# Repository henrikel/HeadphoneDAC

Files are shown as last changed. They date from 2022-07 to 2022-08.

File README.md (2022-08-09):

# HeadphoneDAC
This project started with the purchase of a couple of Chinese DAC modules designed around a PCM1794 DAC from TI. It turned out the DAC module was of quite good quality with genuine parts and a design closely following the datasheet reference design for the analog part. I therefore decided to make a headphone amplifier out of this with USB input. For this reason I had to design and construct the actual headphone amplifier as well as the logic that converts the USB data into an I2S stream that can be read by the DAC. A suitable power supply also had to be designed. All in all, the whole project therefore consists of 4 modules, one logic board with a STM32F411 running the show, one DAC module, one headphone amplifier module and one power supply.

The logic module takes care of converting the USB audio stream into I2S data on a USB full-speed interface. This sets a limit of the maximum sample rate to 96 kHz. It implements the proper way to handle the audio data, i.e., asynchronously. As of now, the system clock of the STM32 microcontroller is used for the audio clock, something that can be improved in the future. The STM32F411 microcontroller also takes care of the user interface, which consists of a few buttons and LEDs to indicate playback, mute and sampling rate. A LED VU meter is also implemented as well as control of a relay to avoid pops and clicks at startup and shutdown.

The headphone amplifier is a class A output design, using a NE5534 opamp as voltage amplifier and an emitter follower implemented as a Sziklai pair with a current sink. The design itself has borrowed from two sources, the Youtube channel Innove Workshop (but modified for dual supply) and Elliott Sound Products (https://sound-au.com/project113.htm). It is a relatively simple design, but measures well (I get THD figures of approximately 0.03% at 1 kHz and 100 mW, which is around the limit of my home made sound card using a Raspberry Pi and Hifiberry ADC+DAC). 

The power supply is a simple design giving +/-12 V and +5V, with a toroidal transformer and LM317/337 and L7812/7809/7805.

I am pretty happy with this build and think it sounds really good with my Beyerdynamic DT880 Pro headphones (250 ohms). I had some problems with ground loops and interference from the transformer in the case I built for the amplifier, but I think I have sorted out most of that now with some tweaking of the orientation of the transformer as well as appropriate grounding. What remains is an irritating high-pitched interference obviously coming from the digital parts of the controller module, which oddly enough can only be heard when muting the sound (if streaming is on, but no music is playing or very low levels of music, I can't hear it).
<p align="center">
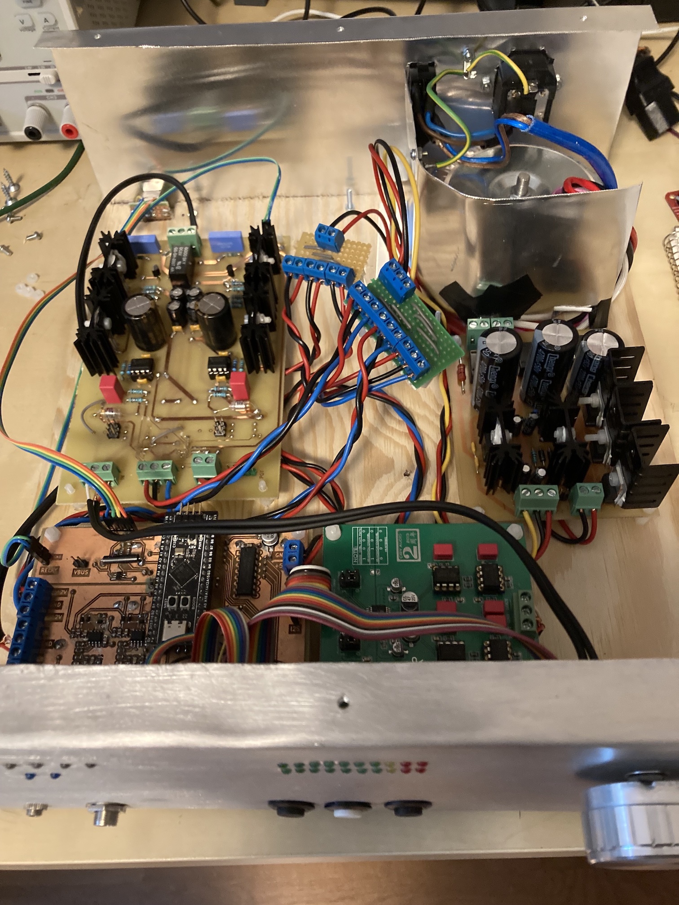
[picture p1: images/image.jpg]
Prototype
  
</p>

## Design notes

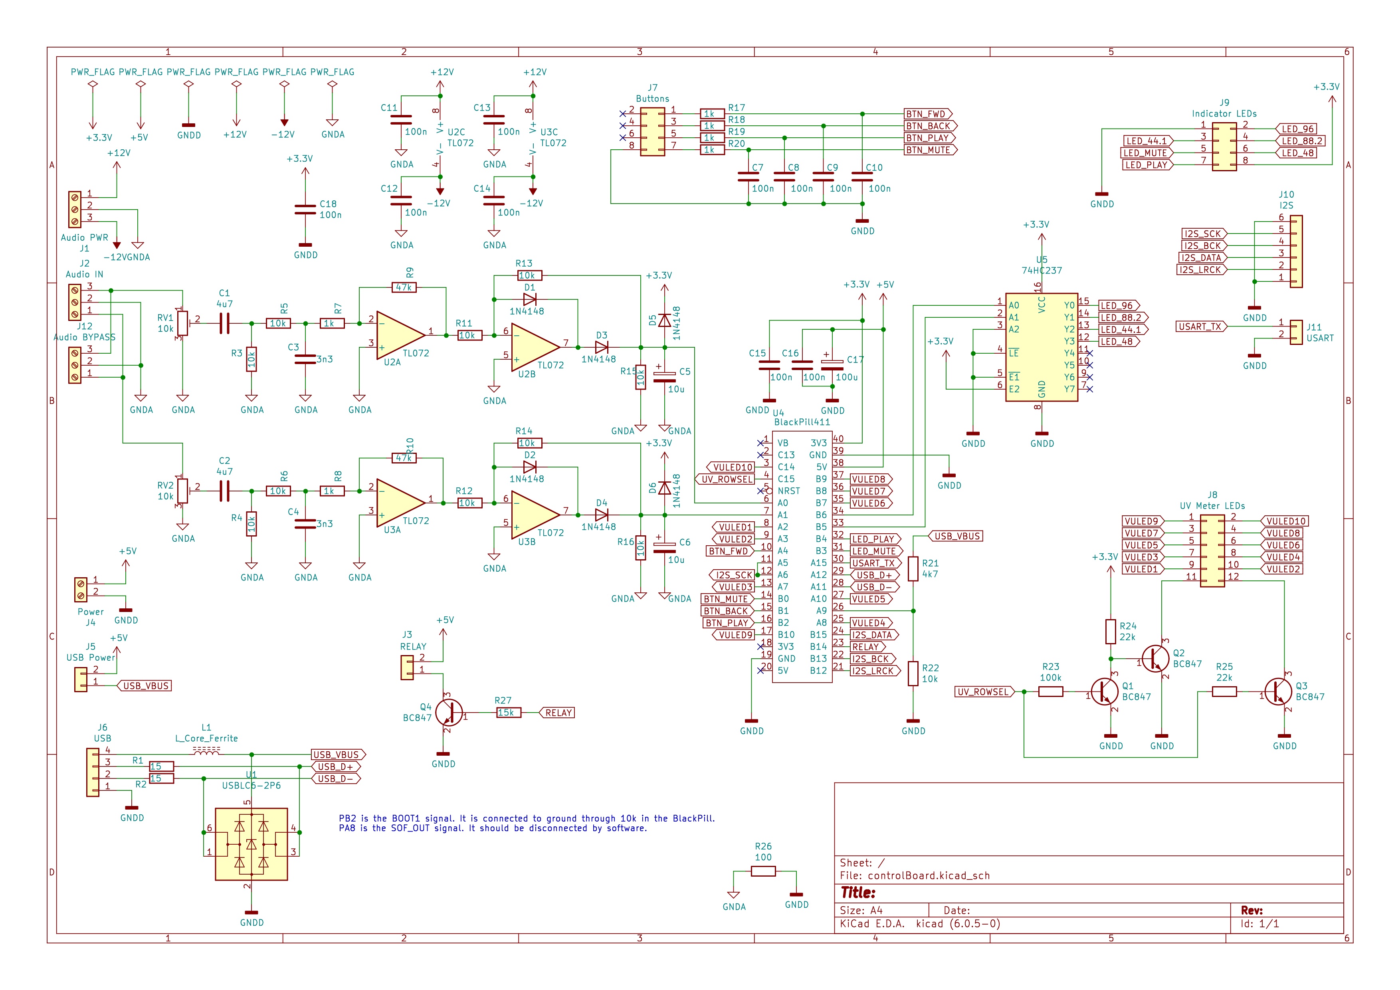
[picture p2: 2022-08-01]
hw/controlBoard/schematic.jpg

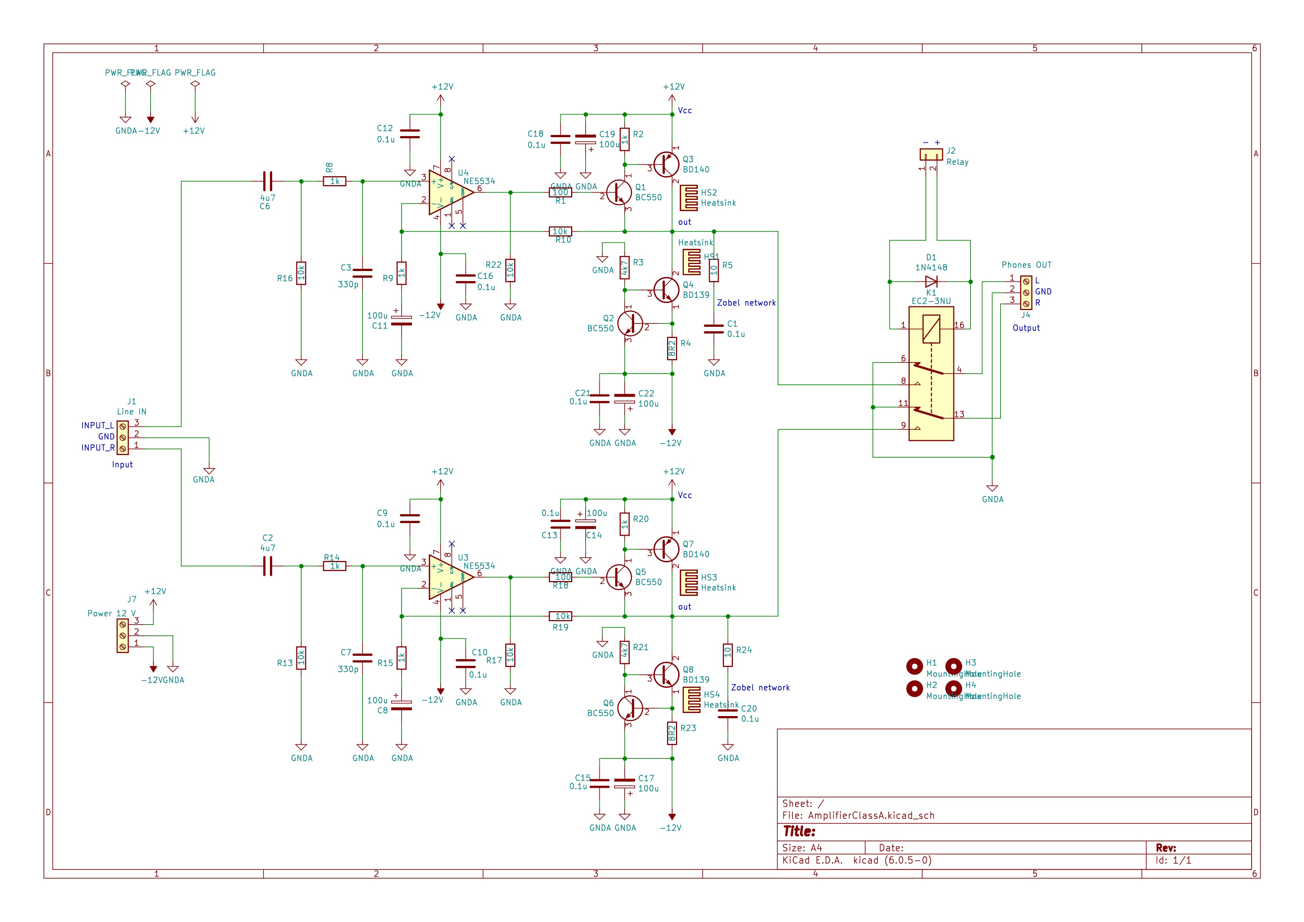
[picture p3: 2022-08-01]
hw/AmplifierClassA/schematic.jpg

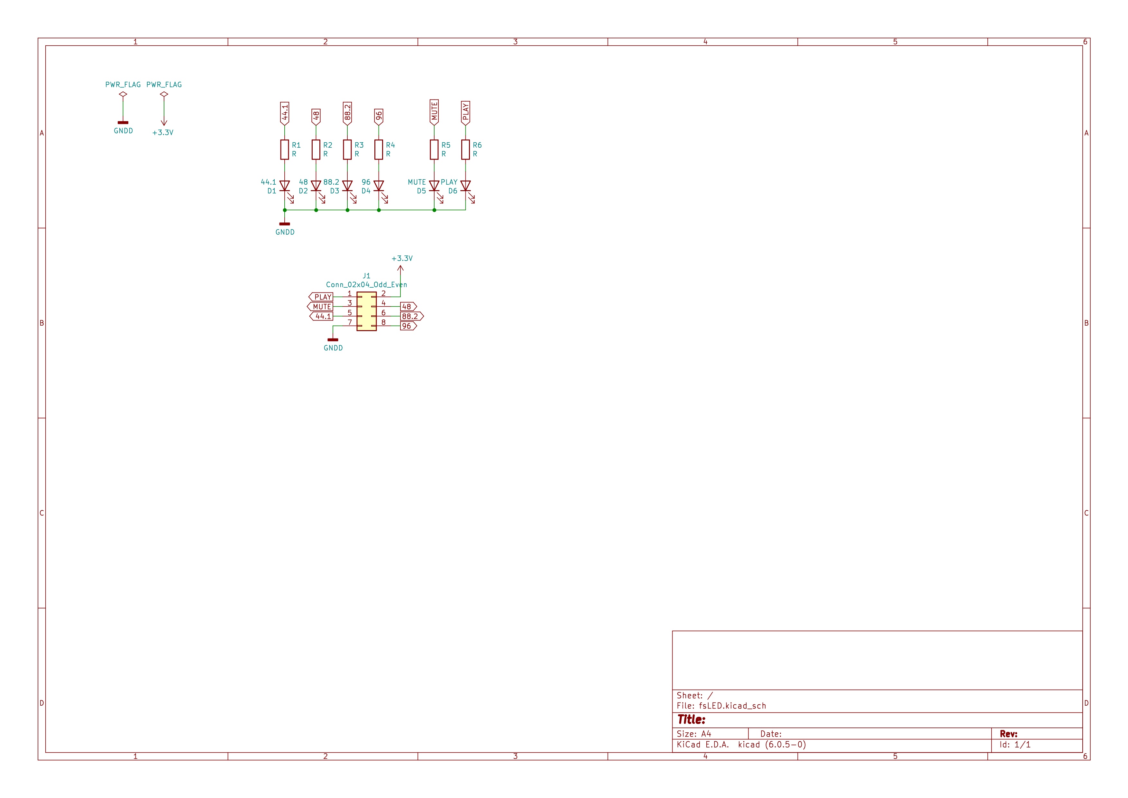
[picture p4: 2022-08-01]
hw/fsLED/schematic.jpg

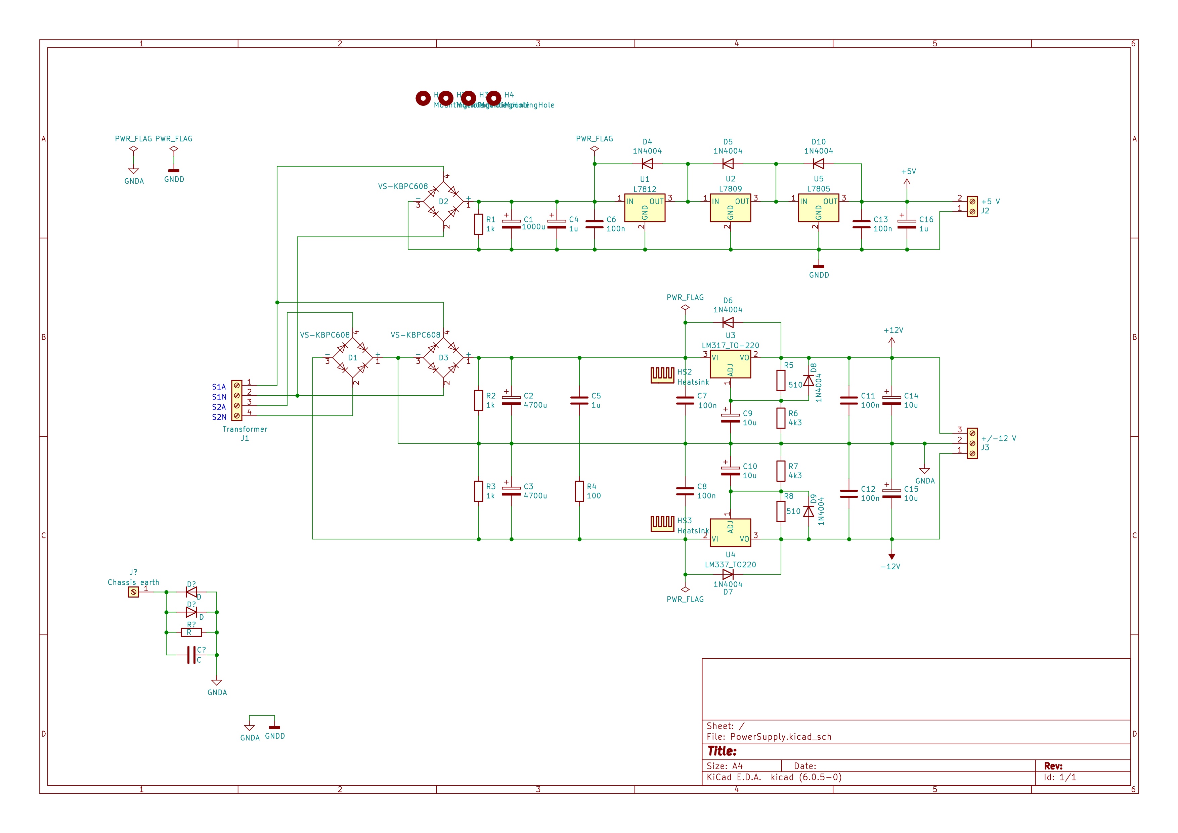
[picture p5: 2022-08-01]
hw/PowerSupply/schematic.jpg

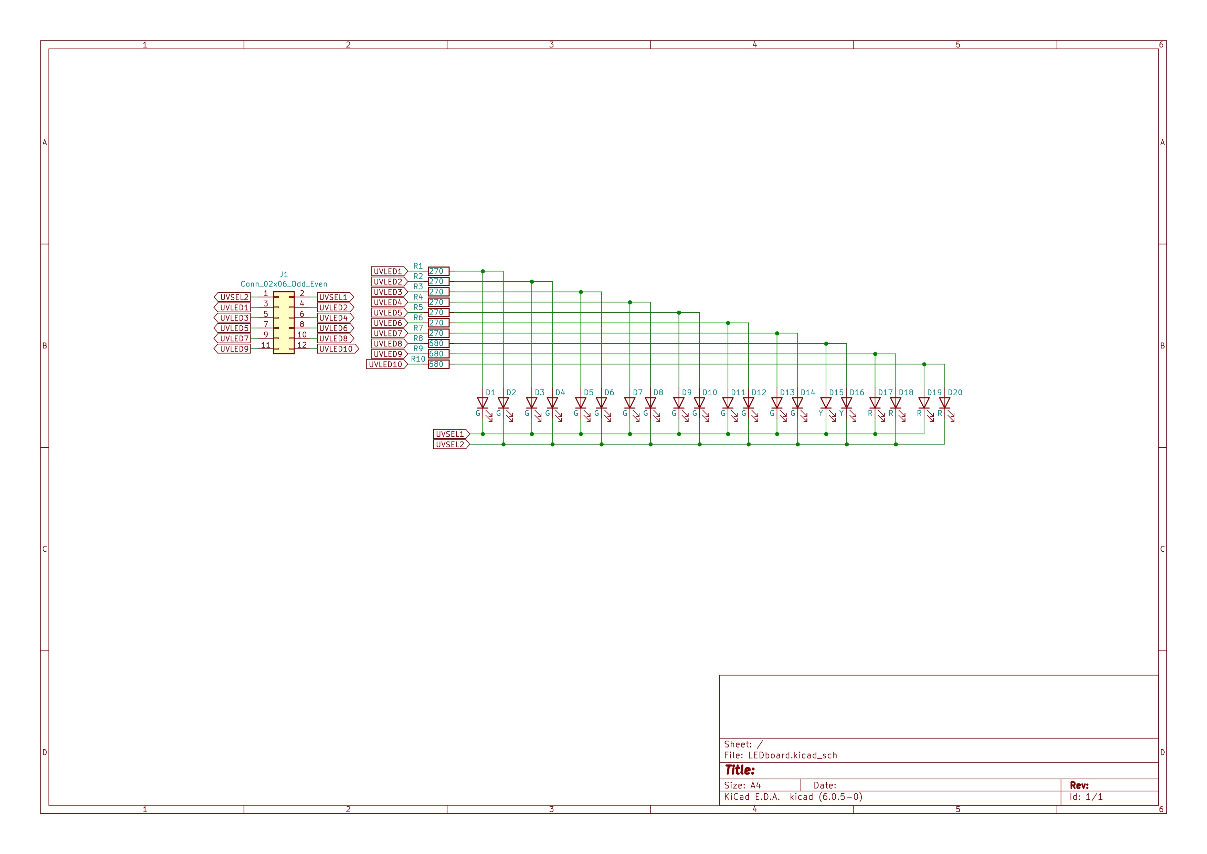
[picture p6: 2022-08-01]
hw/LEDboard/schematic.jpg

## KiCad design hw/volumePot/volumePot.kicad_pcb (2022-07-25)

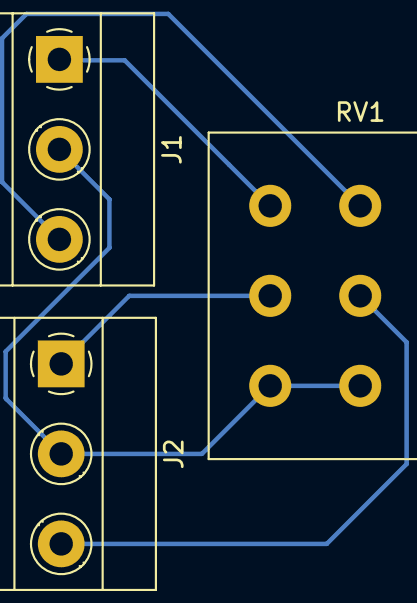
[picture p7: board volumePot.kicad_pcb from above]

Board: 2 copper layers, 3 parts (0 on the bottom side), 5 nets.

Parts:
J1, J2: Screw_Terminal_01x03; TerminalBlock_Phoenix_MKDS-1,5-3_1x03_P5.00mm_Horizontal
RV1: R_POT_Dual; Potentiometer_Alps_RK163_Dual_Horizontal

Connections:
unnamed: J1.1, RV1.6
unnamed: J1.2, J2.2, RV1.1, RV1.4
unnamed: J1.3, RV1.3
unnamed: J2.1, RV1.5
unnamed: J2.3, RV1.2

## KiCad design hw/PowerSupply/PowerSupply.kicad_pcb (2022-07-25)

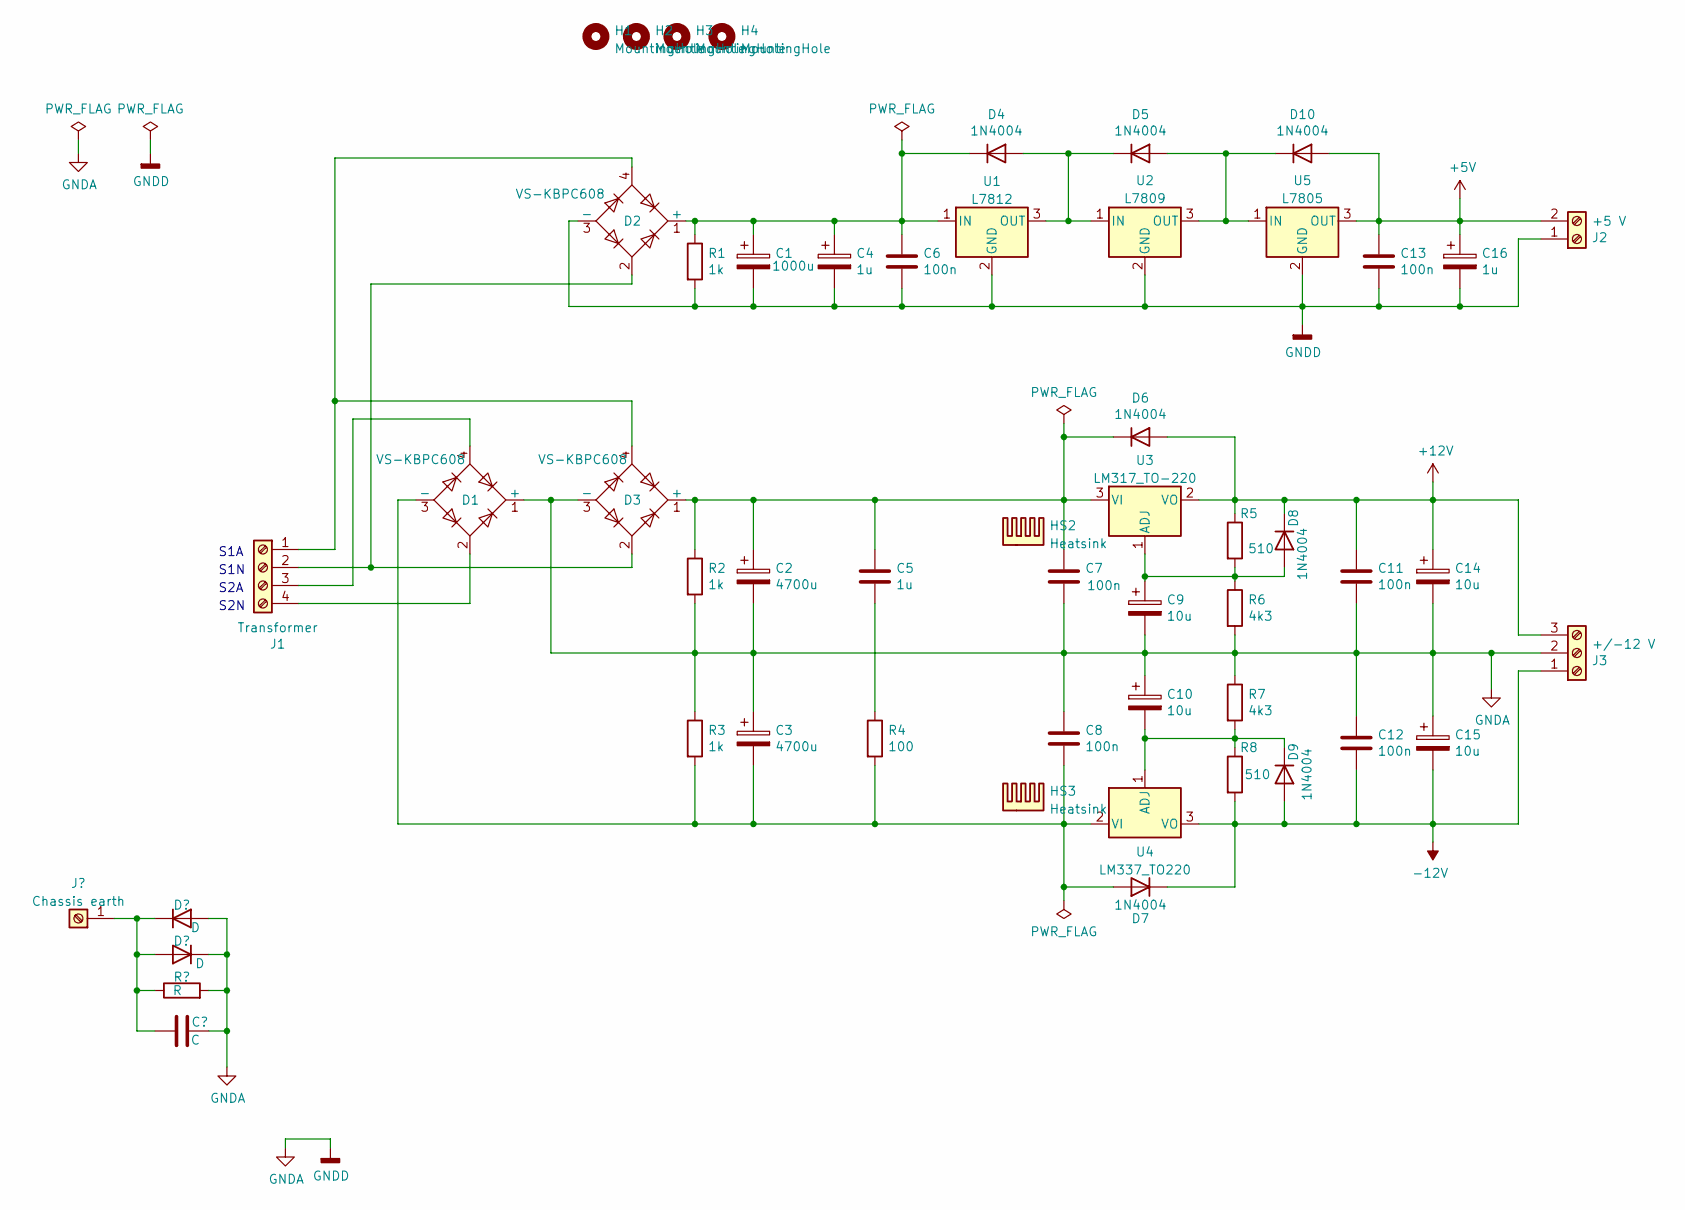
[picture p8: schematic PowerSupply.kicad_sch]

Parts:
C1: 1000u; CP_Radial_D18.0mm_P7.50mm
C2, C3: 4700u; CP_Radial_D18.0mm_P7.50mm
C4, C16: 1u; CP_Radial_D5.0mm_P2.00mm
C5: 1u; C_Rect_L7.0mm_W2.5mm_P5.00mm
C6, C7, C8, C11, C12, C13: 100n; C_Rect_L7.0mm_W2.5mm_P5.00mm
C9, C10, C14, C15: 10u; CP_Radial_D5.0mm_P2.00mm
D1, D2, D3: VS-KBPC608; Diode_Bridge_Vishay_KBPC6
D4, D5, D6, D7, D8, D9, D10: 1N4004; D_DO-41_SOD81_P10.16mm_Horizontal
H1, H2, H3, H4: MountingHole; MountingHole_3.2mm_M3
HS2, HS3: Heatsink; Heatsink_Fischer_SK104-STC-STIC_35x13mm_2xDrill2.5mm
J1: Transformer; TerminalBlock_Phoenix_MKDS-1,5-4_1x04_P5.00mm_Horizontal
J2: +5 V; TerminalBlock_Phoenix_MKDS-1,5-2_1x02_P5.00mm_Horizontal
J3: +/-12 V; TerminalBlock_Phoenix_MKDS-1,5-3_1x03_P5.00mm_Horizontal
R1, R2, R3: 1k; R_Axial_DIN0414_L11.9mm_D4.5mm_P20.32mm_Horizontal
R4: 100; R_Axial_DIN0207_L6.3mm_D2.5mm_P10.16mm_Horizontal
R5, R8: 510; R_Axial_DIN0207_L6.3mm_D2.5mm_P10.16mm_Horizontal
R6, R7: 4k3; R_Axial_DIN0207_L6.3mm_D2.5mm_P10.16mm_Horizontal
U1: L7812; TO-220-3_Vertical
U2: L7809; TO-220-3_Vertical
U3: LM317_TO-220; TO-220-3_Vertical
U4: LM337_TO220; TO-220-3_Vertical
U5: L7805; TO-220-3_Vertical

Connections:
+5V: C13.1, C16.1, D10.2 (A), J2.2, U5.3 (OUT)
+12V: C11.1, C14.1, D6.2 (A), D8.1 (K), J3.3, R5.1, U3.2 (VO)
-12V: C12.2, C15.2, D7.1 (K), D9.2 (A), J3.1, R8.2, U4.3 (VO)
GNDA: C1.2, C2.2, C3.1, C4.2, C6.2, C7.2, C8.1, C9.2, C10.1, C11.2, C12.1, C13.2, C14.2, C15.1, C16.2, D1.1 (+), D2.3 (-), D3.3 (-), J2.1, J3.2, R1.2, R2.2, R3.1, R6.2, R7.1, U1.2 (GND), U2.2 (GND), U5.2 (GND)
unnamed: C1.1, C4.1, C6.1, D2.1 (+), D4.1 (K), R1.1, U1.1 (IN)
unnamed: C2.1, C5.1, C7.1, D3.1 (+), D6.1 (K), R2.1, U3.3 (VI)
unnamed: C3.2, C8.2, D1.3 (-), D7.2 (A), R3.2, R4.2, U4.2 (VI)
unnamed: C5.2, R4.1
unnamed: C9.1, D8.2 (A), R5.2, R6.1, U3.1 (ADJ)
unnamed: C10.2, D9.1 (K), R7.2, R8.1, U4.1 (ADJ)
unnamed: D1.2, J1.4
unnamed: D1.4, J1.3
unnamed: D2.2, D3.2, J1.2
unnamed: D2.4, D3.4, J1.1
unnamed: D4.2 (A), D5.1 (K), U1.3 (OUT), U2.1 (IN)
unnamed: D5.2 (A), D10.1 (K), U2.3 (OUT), U5.1 (IN)

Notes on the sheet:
S1N
S2N
S2A
S1A

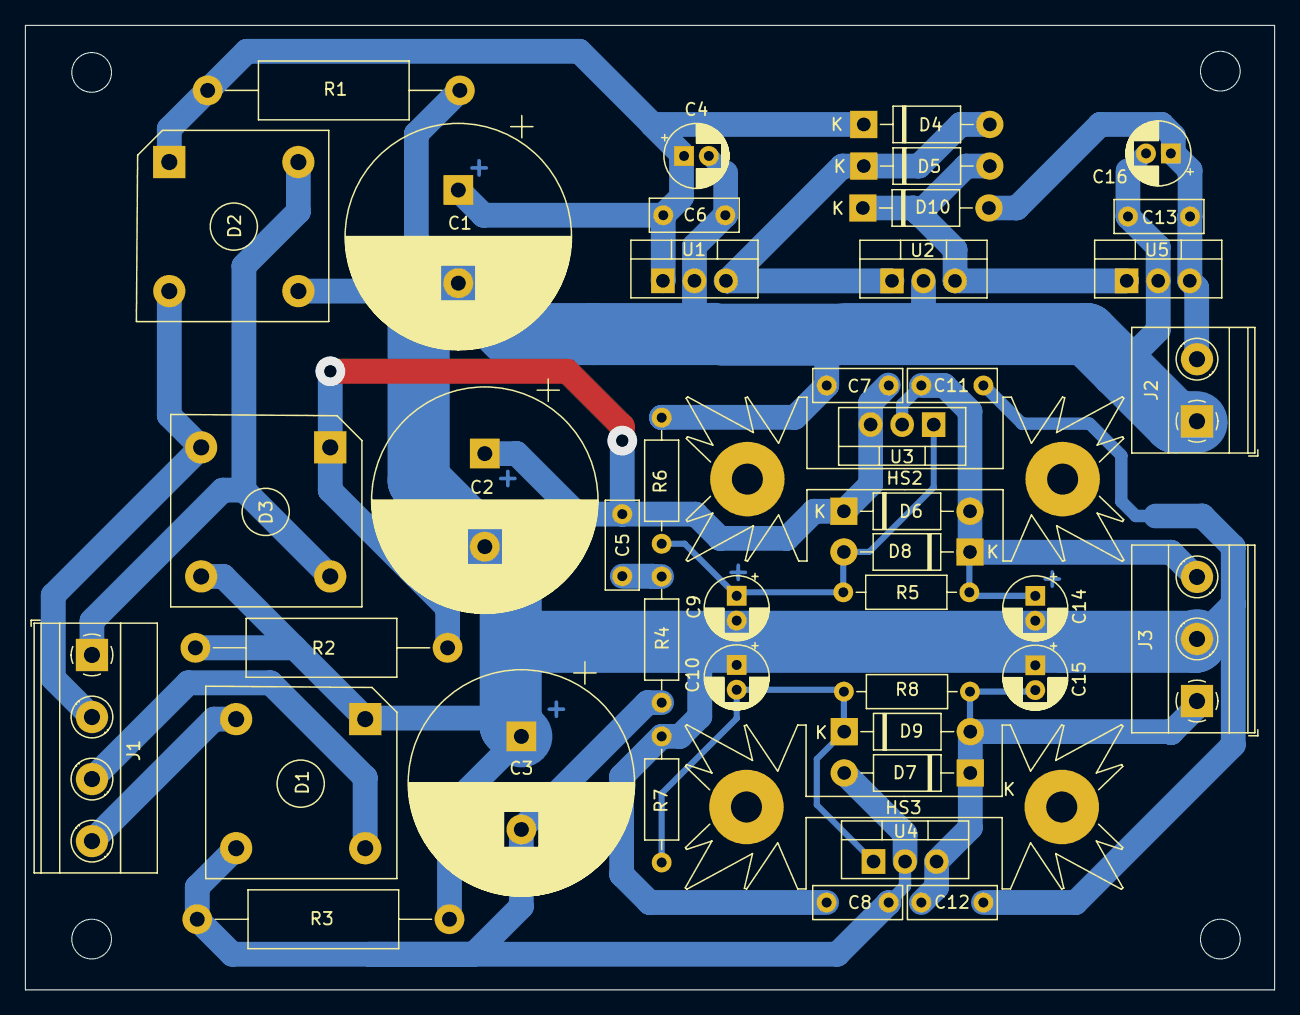
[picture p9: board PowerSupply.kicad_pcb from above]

Board: 2 copper layers, 100.6 x 77.7 mm, 48 parts (0 on the bottom side), 16 nets.

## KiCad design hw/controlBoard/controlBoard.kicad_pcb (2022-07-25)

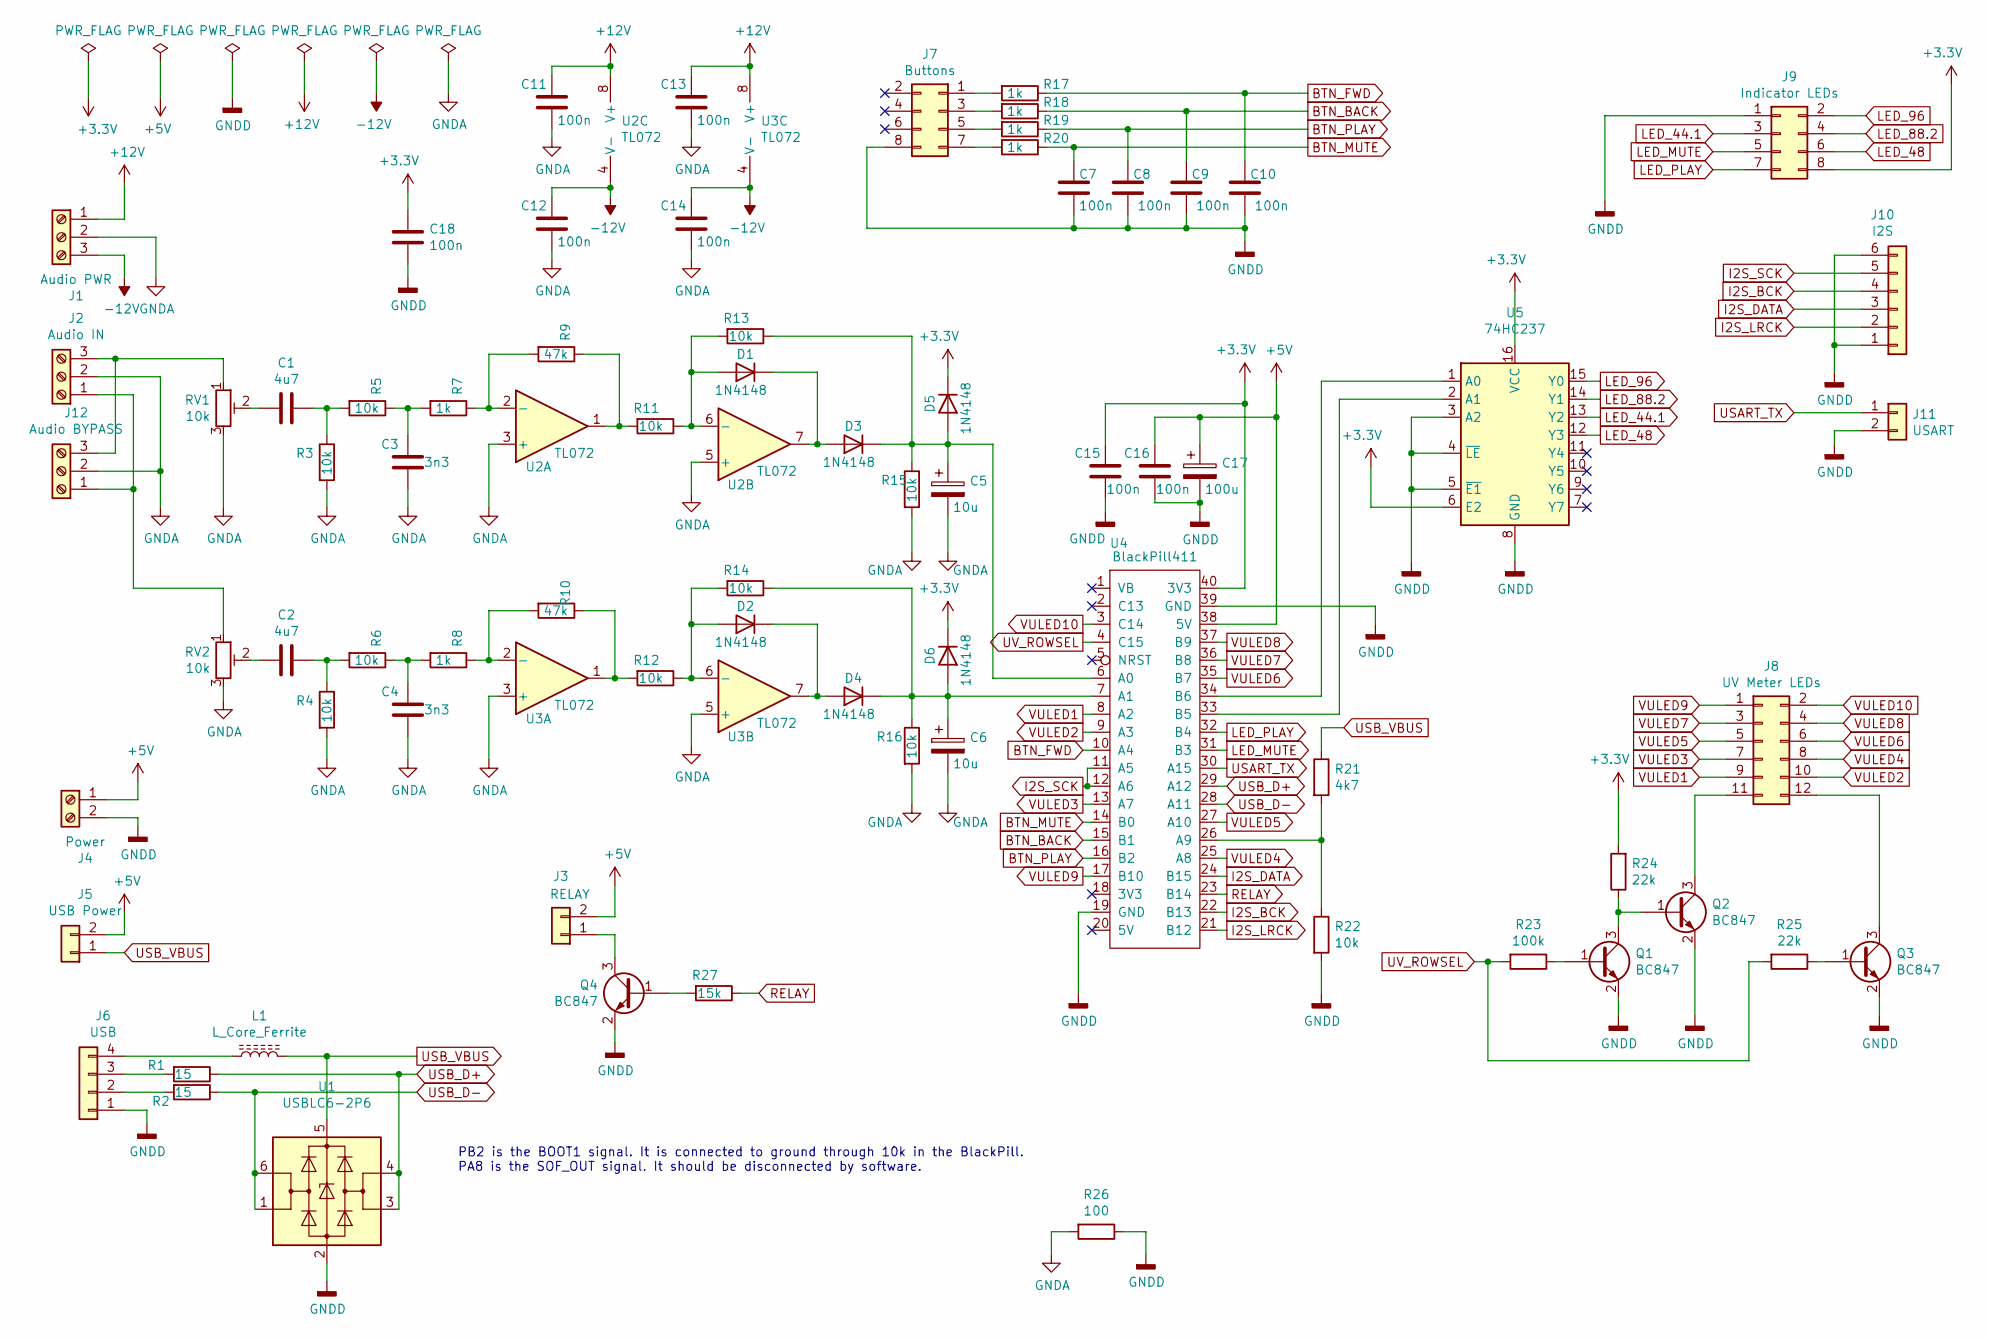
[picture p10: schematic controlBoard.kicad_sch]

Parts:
C1, C2: 4u7; C_0805_2012Metric_Pad1.18x1.45mm_HandSolder
C3, C4: 3n3; C_0805_2012Metric_Pad1.18x1.45mm_HandSolder
C5, C6: 10u; C_0805_2012Metric_Pad1.18x1.45mm_HandSolder
C7, C8, C9, C10, C11, C12, C13, C14, C15, C16, C18: 100n; C_0805_2012Metric_Pad1.18x1.45mm_HandSolder
C17: 100u; CP_Elec_6.3x5.4
D1, D2, D3, D4, D5, D6: 1N4148; D_SOD-323_HandSoldering
J1: Audio PWR; TerminalBlock_bornier-3_P5.08mm
J2: Audio IN; TerminalBlock_bornier-3_P5.08mm
J3: RELAY; PinHeader_1x02_P2.54mm_Vertical
J4: Power; TerminalBlock_bornier-2_P5.08mm
J5: USB Power; PinHeader_1x02_P2.54mm_Vertical
J6: USB; PinHeader_1x04_P2.54mm_Vertical
J7: Buttons; PinHeader_2x04_P2.54mm_Vertical
J8: UV Meter LEDs; PinHeader_2x06_P2.54mm_Vertical
J9: Indicator LEDs; PinHeader_2x04_P2.54mm_Vertical
J10: I2S; PinHeader_1x06_P2.54mm_Vertical
J11: USART; PinHeader_1x02_P2.54mm_Vertical
J12: Audio BYPASS; TerminalBlock_bornier-3_P5.08mm
L1: L_Core_Ferrite; L_Axial_L13.0mm_D4.5mm_P15.24mm_Horizontal_Fastron_HCCC
Q1, Q2, Q3, Q4: BC847; SOT-23
R1, R2: 15; R_0805_2012Metric_Pad1.20x1.40mm_HandSolder
R3, R4, R5, R6, R11, R12, R13, R14, R15, R16, R22: 10k; R_0805_2012Metric_Pad1.20x1.40mm_HandSolder
R7, R8: 1k; R_0805_2012Metric_Pad1.20x1.40mm_HandSolder
R9, R10: 47k; R_0805_2012Metric_Pad1.20x1.40mm_HandSolder
R17, R18, R19, R20: 1k; R_Axial_DIN0207_L6.3mm_D2.5mm_P10.16mm_Horizontal
R21: 4k7; R_0805_2012Metric_Pad1.20x1.40mm_HandSolder
R23: 100k; R_0805_2012Metric_Pad1.20x1.40mm_HandSolder
R24, R25: 22k; R_0805_2012Metric_Pad1.20x1.40mm_HandSolder
R26: 100; R_0805_2012Metric_Pad1.20x1.40mm_HandSolder
R27: 15k; R_0805_2012Metric_Pad1.20x1.40mm_HandSolder
RV1, RV2: 10k; Potentiometer_Piher_PT-10-V10_Vertical
U1: USBLC6-2P6; TSOT-23-6_HandSoldering
U2, U3: TL072; SO-8_3.9x4.9mm_P1.27mm
U4: BlackPill411
U5: 74HC237; DIP-16_W7.62mm_Socket_LongPads

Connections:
+3V3: C15.2, C18.1, D5.1 (K), D6.1 (K), J9.8, R24.2, U4.40 (3V3), U5.6 (E2), U5.16 (VCC)
+5V: C16.2, C17.1, J3.2, J4.1, J5.2, U4.38 (5V)
+12V: C11.2, C13.2, J1.1, U2.8 (V+), U3.8 (V+)
-12V: C12.2, C14.2, J1.3, U2.4 (V-), U3.4 (V-)
BTN_BACK: C9.1, R18.1, U4.15 (B1)
BTN_FWD: C10.1, R17.1, U4.10 (A4)
BTN_MUTE: C7.1, R20.1, U4.14 (B0)
BTN_PLAY: C8.1, R19.1, U4.16 (B2)
GNDA: C3.1, C4.1, C5.2, C6.2, C11.1, C12.1, C13.1, C14.1, J1.2, J2.2, J12.2, R3.2, R4.2, R15.2, R16.2, R26.2, RV1.3, RV2.3, U2.3 (+), U2.5 (+), U3.3 (+), U3.5 (+)
GNDD: C7.2, C8.2, C9.2, C10.2, C15.1, C16.1, C17.2, C18.2, J4.2, J6.1, J7.8, J9.1, J10.1, J10.6, J11.2, Q1.2 (E), Q2.2 (E), Q3.2 (E), Q4.2 (E), R22.2, R26.1, U1.2 (GND), U4.19 (GND), U4.39 (GND), U5.3 (A2), U5.4 (~LE), U5.5 (~E1), U5.8 (GND)
I2S_BCK: J10.4, U4.22 (B13)
I2S_DATA: J10.3, U4.24 (B15)
I2S_LRCK: J10.2, U4.21 (B12)
I2S_SCK: J10.5, U4.11 (A5), U4.12 (A6)
LED_44.1: J9.3, U5.13 (Y2)
LED_48: J9.6, U5.12 (Y3)
LED_88.2: J9.4, U5.14 (Y1)
LED_96: J9.2, U5.15 (Y0)
LED_MUTE: J9.5, U4.31 (B3)
LED_PLAY: J9.7, U4.32 (B4)
unnamed: C1.1, R3.1, R5.2
unnamed: C1.2, RV1.2
unnamed: C2.1, R4.1, R6.2
unnamed: C2.2, RV2.2
unnamed: C3.2, R5.1, R7.2
unnamed: C4.2, R6.1, R8.2
unnamed: C5.1, D3.1 (K), D5.2 (A), R13.1, R15.1, U4.6 (A0)
unnamed: C6.1, D4.1 (K), D6.2 (A), R14.1, R16.1, U4.7 (A1)
unnamed: D1.1 (K), D3.2 (A), U2.7
unnamed: D1.2 (A), R11.1, R13.2, U2.6 (-)
unnamed: D2.1 (K), D4.2 (A), U3.7
unnamed: D2.2 (A), R12.1, R14.2, U3.6 (-)
unnamed: J3.1, Q4.3 (C)
unnamed: J6.2, R2.2
unnamed: J6.3, R1.2
unnamed: J6.4, L1.1
unnamed: J7.1, R17.2
unnamed: J7.3, R18.2
unnamed: J7.5, R19.2
unnamed: J7.7, R20.2
unnamed: J8.11, Q2.3 (C)
unnamed: J8.12, Q3.3 (C)
unnamed: J2.1, J12.1, RV2.1
unnamed: J2.3, J12.3, RV1.1
unnamed: Q1.1 (B), R23.1
unnamed: Q1.3 (C), Q2.1 (B), R24.1
unnamed: Q3.1 (B), R25.1
unnamed: Q4.1 (B), R27.2
unnamed: R7.1, R9.2, U2.2 (-)
unnamed: R10.1, R12.2, U3.1
unnamed: R8.1, R10.2, U3.2 (-)
unnamed: R9.1, R11.2, U2.1
unnamed: R21.2, R22.1, U4.26 (A9)
unnamed: U4.33 (B5), U5.2 (A1)
unnamed: U4.34 (B6), U5.1 (A0)
RELAY: R27.1, U4.23 (B14)
USART_TX: J11.1, U4.30 (A15)
USB_D+: R1.1, U1.3 (I/O2), U1.4 (I/O2), U4.29 (A12)
USB_D-: R2.1, U1.1 (I/O1), U1.6 (I/O1), U4.28 (A11)
USB_VBUS: J5.1, L1.2, R21.1, U1.5 (VBUS)
UV_ROWSEL: R23.2, R25.2, U4.4 (C15)
VULED1: J8.9, U4.8 (A2)
VULED2: J8.10, U4.9 (A3)
VULED3: J8.7, U4.13 (A7)
VULED4: J8.8, U4.25 (A8)
VULED5: J8.5, U4.27 (A10)
VULED6: J8.6, U4.35 (B7)
VULED7: J8.3, U4.36 (B8)
VULED8: J8.4, U4.37 (B9)
VULED9: J8.1, U4.17 (B10)
VULED10: J8.2, U4.3 (C14)

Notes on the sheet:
PB2 is the BOOT1 signal. It is connected to ground through 10k in the BlackPill. PA8 is the SOF_OUT signal. It should be disconnected by software.

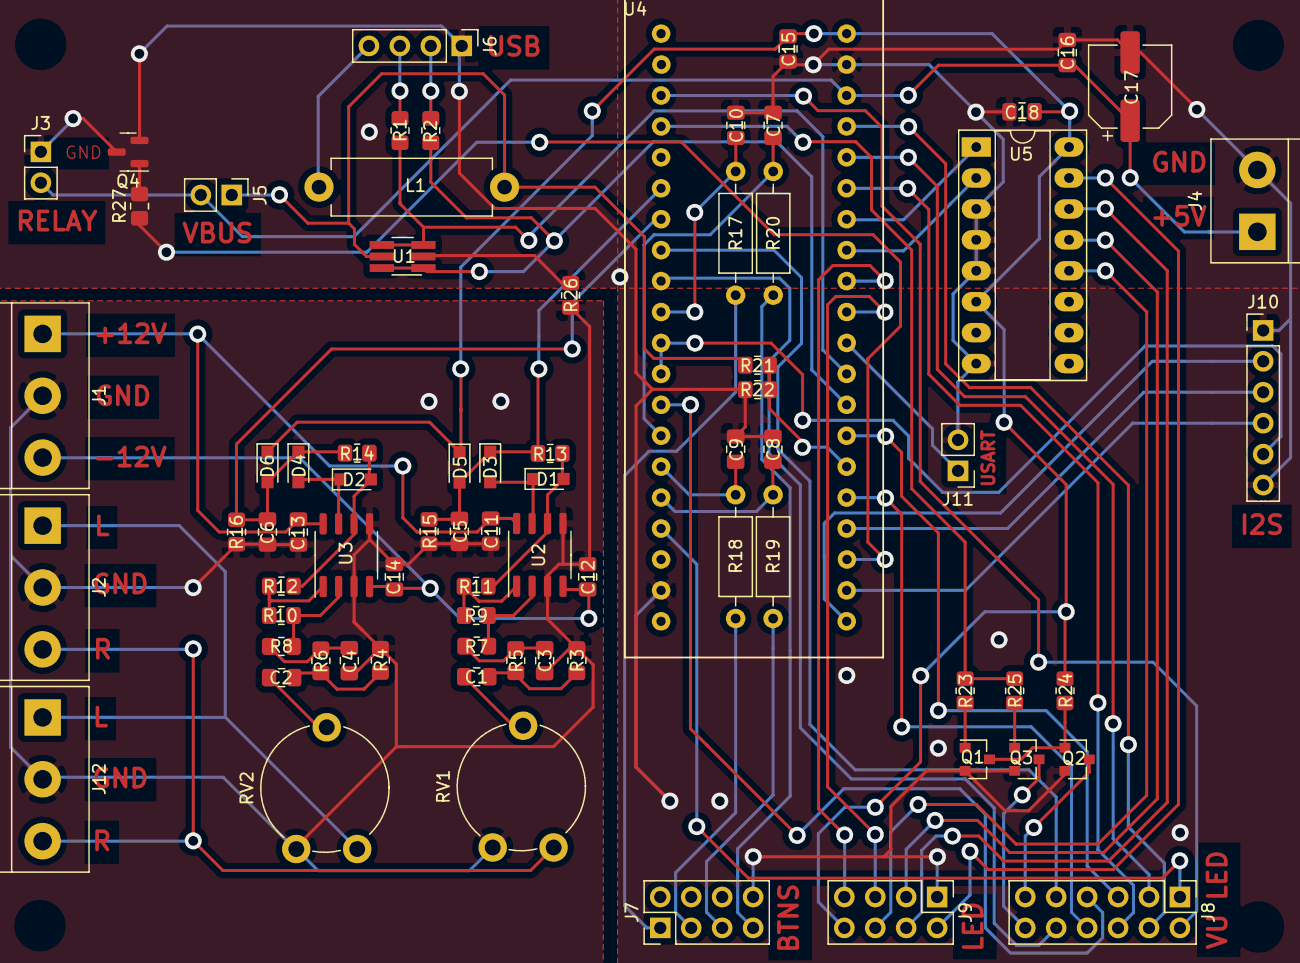
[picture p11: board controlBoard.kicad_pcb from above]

Board: 2 copper layers, 75 parts (0 on the bottom side), 71 nets.

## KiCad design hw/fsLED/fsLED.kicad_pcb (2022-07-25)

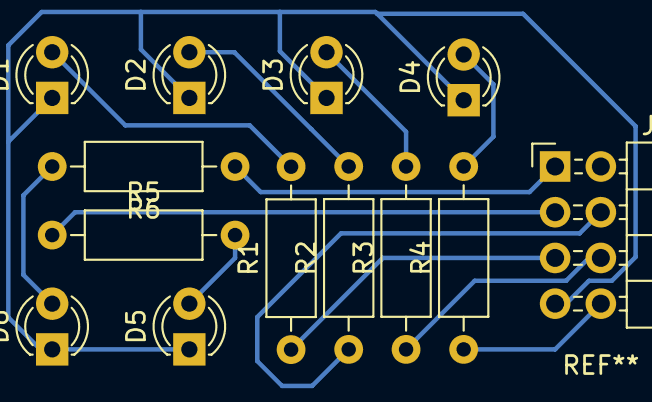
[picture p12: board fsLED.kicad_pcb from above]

Board: 2 copper layers, 13 parts (0 on the bottom side), 13 nets.

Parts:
D1: 44.1; LED_D3.0mm
D2: 48; LED_D3.0mm
D3: 88.2; LED_D3.0mm
D4: 96; LED_D3.0mm
D5: MUTE; LED_D3.0mm
D6: PLAY; LED_D3.0mm
J1: Conn_02x04_Odd_Even; PinHeader_2x04_P2.54mm_Horizontal
R1, R2, R3, R4, R5, R6: R; R_Axial_DIN0207_L6.3mm_D2.5mm_P10.16mm_Horizontal

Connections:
44.1: J1.5, R1.1
48: J1.4, R2.1
88.2: J1.6, R3.1
96: J1.8, R4.1
GNDD: D1.1, D2.1, D3.1, D4.1, D5.1, D6.1, J1.7
MUTE: J1.3, R5.1
unnamed: D1.2, R1.2
unnamed: D2.2, R2.2
unnamed: D3.2, R3.2
unnamed: D4.2, R4.2
unnamed: D5.2, R5.2
unnamed: D6.2, R6.2
PLAY: J1.1, R6.1

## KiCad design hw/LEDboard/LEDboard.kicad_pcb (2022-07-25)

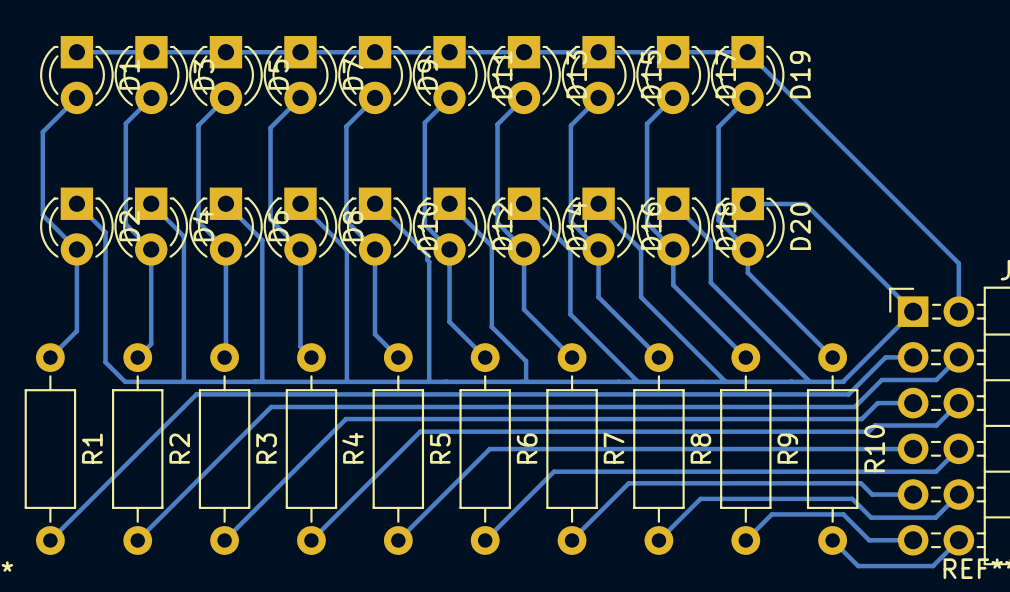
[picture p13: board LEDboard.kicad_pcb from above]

Board: 2 copper layers, 31 parts (0 on the bottom side), 22 nets.

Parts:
D1, D2, D3, D4, D5, D6, D7, D8, D9, D10, D11, D12, D13, D14: G; LED_D3.0mm
D15, D16: Y; LED_D3.0mm
D17, D18, D19, D20: R; LED_D3.0mm
J1: Conn_02x06_Odd_Even; PinHeader_2x06_P2.54mm_Horizontal
R1, R2, R3, R4, R5, R6, R7: 270; R_Axial_DIN0207_L6.3mm_D2.5mm_P10.16mm_Horizontal
R8: 330; R_Axial_DIN0207_L6.3mm_D2.5mm_P10.16mm_Horizontal
R9, R10: 390; R_Axial_DIN0207_L6.3mm_D2.5mm_P10.16mm_Horizontal

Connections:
unnamed: D1.2, D2.2, R1.1
unnamed: D3.2, D4.2, R2.1
unnamed: D5.2, D6.2, R3.1
unnamed: D7.2, D8.2, R4.1
unnamed: D9.2, D10.2, R5.1
unnamed: D11.2, D12.2, R6.1
unnamed: D13.2, D14.2, R7.1
unnamed: D15.2, D16.2, R8.1
unnamed: D17.2, D18.2, R9.1
unnamed: D19.2, D20.2, R10.1
UVLED1: J1.3, R1.2
UVLED2: J1.4, R2.2
UVLED3: J1.5, R3.2
UVLED4: J1.6, R4.2
UVLED5: J1.7, R5.2
UVLED6: J1.8, R6.2
UVLED7: J1.9, R7.2
UVLED8: J1.10, R8.2
UVLED9: J1.11, R9.2
UVLED10: J1.12, R10.2
UVSEL1: D1.1, D3.1, D5.1, D7.1, D9.1, D11.1, D13.1, D15.1, D17.1, D19.1, J1.2
UVSEL2: D2.1, D4.1, D6.1, D8.1, D10.1, D12.1, D14.1, D16.1, D18.1, D20.1, J1.1

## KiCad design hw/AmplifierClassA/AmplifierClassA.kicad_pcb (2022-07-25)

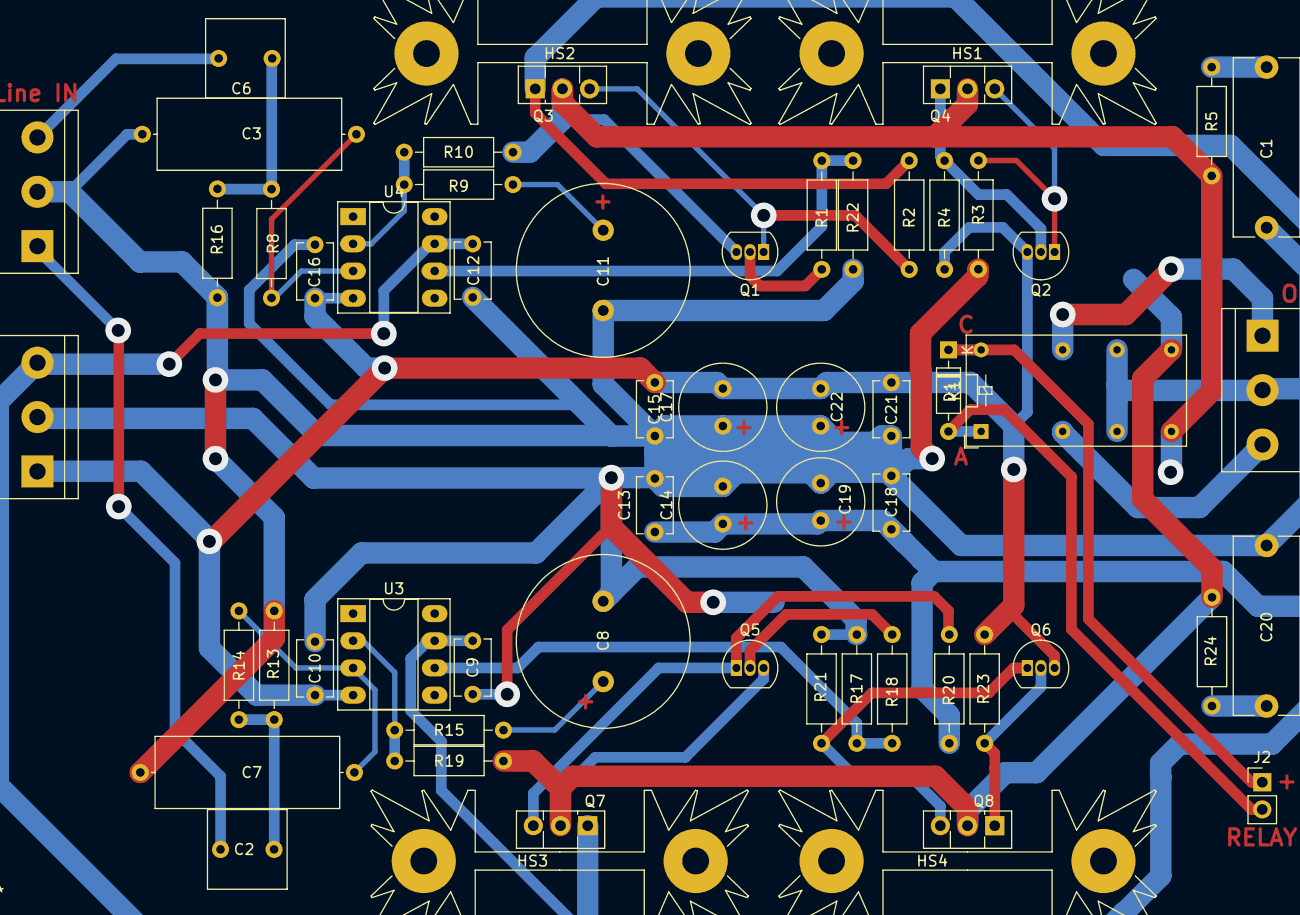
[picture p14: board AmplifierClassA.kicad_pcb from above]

Board: 2 copper layers, 60 parts (0 on the bottom side), 31 nets.

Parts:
C1, C20: 0.1u; C_Rect_L16.5mm_W6.0mm_P15.00mm_MKT
C2, C6: 4u7; C_Rect_L7.2mm_W7.2mm_P5.00mm_FKS2_FKP2_MKS2_MKP2
C3, C7: 330p; C_Axial_L17.0mm_D6.5mm_P20.00mm_Horizontal
C8, C11: 100u; C_Radial_D16.0mm_H25.0mm_P7.50mm
C9, C10, C12, C13, C15, C16, C18, C21: 0.1u; C_Disc_D5.1mm_W3.2mm_P5.00mm
C14, C17, C19, C22: 100u; C_Radial_D8.0mm_H11.5mm_P3.50mm
D1: 1N4148; D_DO-35_SOD27_P7.62mm_Horizontal
HS1, HS2, HS3, HS4: Heatsink; Heatsink_Fischer_SK104-STC-STIC_35x13mm_2xDrill2.5mm
J1: Line IN; TerminalBlock_bornier-3_P5.08mm
J2: Relay; PinHeader_1x02_P2.54mm_Vertical
J4: Phones OUT; TerminalBlock_bornier-3_P5.08mm
J7: Power 12 V; TerminalBlock_bornier-3_P5.08mm
K1: EC2-3NU; Relay_DPDT_Omron_G5V-2
Q1, Q2, Q5, Q6: BC550; TO-92_Inline
Q3, Q7: BD140; TO-126-3_Vertical
Q4, Q8: BD139; TO-126-3_Vertical
R1, R18: 100; R_Axial_DIN0207_L6.3mm_D2.5mm_P10.16mm_Horizontal
R2, R8, R14, R20: 1k; R_Axial_DIN0207_L6.3mm_D2.5mm_P10.16mm_Horizontal
R3, R21: 4k7; R_Axial_DIN0207_L6.3mm_D2.5mm_P10.16mm_Horizontal
R4, R23: 5R6; R_Axial_DIN0207_L6.3mm_D2.5mm_P10.16mm_Horizontal
R5, R24: 10; R_Axial_DIN0207_L6.3mm_D2.5mm_P10.16mm_Horizontal
R9, R15: 3k; R_Axial_DIN0207_L6.3mm_D2.5mm_P10.16mm_Horizontal
R10, R13, R16, R17, R19, R22: 10k; R_Axial_DIN0207_L6.3mm_D2.5mm_P10.16mm_Horizontal
U3, U4: NE5534; DIP-8_W7.62mm_Socket_LongPads

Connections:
+12V: C9.1, C12.1, C13.1, C14.1, C18.1, C19.2, J7.3, Q3.1 (E), Q7.1 (E), R2.1, R20.1, U3.7 (V+), U4.7 (V+)
-12V: C10.1, C15.1, C16.1, C17.2, C21.1, C22.2, J7.1, Q2.3 (E), Q6.3 (E), R4.2, R23.2, U3.4 (V-), U4.4 (V-)
GNDA: C1.2, C3.1, C7.1, C8.2, C9.2, C10.2, C11.2, C12.2, C13.2, C14.2, C15.2, C16.2, C17.1, C18.2, C19.1, C20.2, C21.2, C22.1, J1.2, J4.2, J7.2, K1.6, K1.11, R3.1, R13.1, R16.1, R17.1, R21.1, R22.1
unnamed: C1.1, R5.2
unnamed: C2.1, R13.2, R14.1
unnamed: C2.2, J1.1
unnamed: C3.2, R8.2, U4.3 (+)
unnamed: C6.1, R8.1, R16.2
unnamed: C6.2, J1.3
unnamed: C7.2, R14.2, U3.3 (+)
unnamed: C8.1, R15.1
unnamed: C11.1, R9.1
unnamed: C20.1, R24.2
unnamed: D1.1 (K), J2.1, K1.16
unnamed: D1.2 (A), J2.2, K1.1
unnamed: J4.1, K1.13
unnamed: J4.3, K1.4
unnamed: K1.8, Q1.3 (E), Q3.2 (C), Q4.2 (C), R5.1, R10.1
unnamed: K1.9, Q5.3 (E), Q7.2 (C), Q8.2 (C), R19.1, R24.1
unnamed: Q1.1 (C), Q3.3 (B), R2.2
unnamed: Q1.2 (B), R1.1
unnamed: Q2.1 (C), Q4.3 (B), R3.2
unnamed: Q2.2 (B), Q4.1 (E), R4.1
unnamed: Q5.1 (C), Q7.3 (B), R20.2
unnamed: Q5.2 (B), R18.1
unnamed: Q6.1 (C), Q8.3 (B), R21.2
unnamed: Q6.2 (B), Q8.1 (E), R23.1
unnamed: R1.2, R22.2, U4.6
unnamed: R9.2, R10.2, U4.2 (-)
unnamed: R15.2, R19.2, U3.2 (-)
unnamed: R17.2, R18.2, U3.6

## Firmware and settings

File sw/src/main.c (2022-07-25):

#include "stm32f4xx.h"
#include "utils.h"
#include "audio.h"
#include "adc.h"
#include "ledRamp.h"
#include "shutdownCtl.h"
#ifdef DEBUG
#include "usart.h"
#endif
#include "debounce.h"
#include "usb_streamer.h"

void ClockInit(void) {

	//unsigned int	ra;
	int			tmpReg;

	// Clock initialization
	RCC->CIR = 0x00bf0000;
	
	// Turn on HSE clock
	RCC->CR |= RCC_CR_HSEON;
	while(!(RCC->CR & RCC_CR_HSERDY));
	
	/* set voltage scale to 1 for max frequency */
    /* first enable power interface clock (APB1ENR:bit 28) */
    RCC->APB1ENR |= RCC_APB1ENR_PWREN;

    /* then set voltage scale to 1 for max frequency (PWR_CR:bit 14 and 15)
     * (0) scale 2 for fCLK <= 144 Mhz
     * (1) scale 1 for 144 Mhz < fCLK <= 168 Mhz
     */
    PWR->CR |= 3 << PWR_CR_VOS_Pos; //(3 << 14);
	
	// Configure PLL
	// M = 4, N = 192, P = 2, Q = 4
	// Gives a system clock of 96 MHz
	tmpReg = RCC->PLLCFGR;
	tmpReg &= ~RCC_PLLCFGR_PLLM;
	tmpReg |= 25 << RCC_PLLCFGR_PLLM_Pos;
	
	tmpReg &= ~RCC_PLLCFGR_PLLN;
	tmpReg |= 192 << RCC_PLLCFGR_PLLN_Pos;
	
	tmpReg &= ~RCC_PLLCFGR_PLLP;
	tmpReg |= ((2 >> 1) - 1) << RCC_PLLCFGR_PLLP_Pos;
	
	tmpReg &= ~RCC_PLLCFGR_PLLQ;
	tmpReg |= 4 << RCC_PLLCFGR_PLLQ_Pos;
	
	// Cortex system timer??? 1 or 8?
	
	// Set HSE as PLL source
	tmpReg |= RCC_PLLCFGR_PLLSRC_HSE;
	RCC->PLLCFGR = tmpReg;
	
	// PLL On
	RCC->CR |= RCC_CR_PLLON;
	while(!(RCC->CR & RCC_CR_PLLRDY));
	
	// AHB prescaler = 1, APB1 prescaler = 2, APB2 prescaler = 1
	// AHB prescaler
	tmpReg = RCC->CFGR;
	tmpReg &= ~(RCC_CFGR_HPRE); //remove old prescaler 
	tmpReg |= RCC_CFGR_HPRE_DIV1; //set AHB prescaler = 1. 
	
	//set APB1 prescaler
	tmpReg &= ~(RCC_CFGR_PPRE1);
	tmpReg |= RCC_CFGR_PPRE1_DIV2;
	
	//set APB2 prescaler
	tmpReg &= ~(RCC_CFGR_PPRE2);
	tmpReg |= RCC_CFGR_PPRE2_DIV1;
	RCC->CFGR = tmpReg;
	
	//set flash wait states to 2
	tmpReg = FLASH->ACR;
	tmpReg &= ~(FLASH_ACR_LATENCY); 
	tmpReg |= FLASH_ACR_LATENCY_2WS;
	FLASH->ACR = tmpReg;
	
	// Set system to PLL clock
	RCC->CFGR = (RCC->CFGR & ~(RCC_CFGR_SW)) | RCC_CFGR_SW_PLL;
	while((RCC->CFGR & RCC_CFGR_SWS) != RCC_CFGR_SWS_PLL);
	
	// Set I2S PLL dividers to:
	// M = 25, N = 344, R = 2
	// This gives an I2S clock of  25 MHz / 25 * 344 / 2 = 172 MHz
	// and a sampling frequency of fs = 95.982 kHz when I2SDIV = 3 and I2SODD = 1
	// In this case, MCLK = I2S clock / (2 * I2SDIV + I2SODD)
	// MCLK is 256xfs
	//
	tmpReg = RCC->PLLI2SCFGR;
	tmpReg &= ~RCC_PLLI2SCFGR_PLLI2SR;
	tmpReg |= 2 << RCC_PLLI2SCFGR_PLLI2SR_Pos;
	
	tmpReg &= ~RCC_PLLI2SCFGR_PLLI2SN;
	tmpReg |= 344 << RCC_PLLI2SCFGR_PLLI2SN_Pos;
	
	tmpReg &= ~RCC_PLLI2SCFGR_PLLI2SM;
	tmpReg |= 25 << RCC_PLLI2SCFGR_PLLI2SM_Pos;
	RCC->PLLI2SCFGR = tmpReg;
	
	// Enable the I2S PLL
	RCC->CR |= RCC_CR_PLLI2SON;
	while(!(RCC->CR & RCC_CR_PLLI2SRDY));
	
	// Clear All Interrupts
	RCC->CIR = 0x00df0000;
	
}

void GPIOInit() {
	
	// Enable all relevant GPIO ports
	RCC->AHB1ENR |= RCC_AHB1ENR_GPIOAEN;
	RCC->AHB1ENR |= RCC_AHB1ENR_GPIOBEN;
	RCC->AHB1ENR |= RCC_AHB1ENR_GPIOCEN;
	
	// ADC pin A0 and A1 enable
	GPIOA->OTYPER &= ~GPIO_OTYPER_OT0;
	GPIOA->PUPDR &= ~GPIO_PUPDR_PUPDR0;
	GPIOA->OSPEEDR &= ~GPIO_OSPEEDR_OSPEED0;
	GPIOA->MODER &= ~GPIO_MODER_MODER0;
	GPIOA->MODER |= (3 << GPIO_MODER_MODER0_Pos);
	
	GPIOA->OTYPER &= ~GPIO_OTYPER_OT1;
	GPIOA->PUPDR &= ~GPIO_PUPDR_PUPDR1;
	GPIOA->OSPEEDR &= ~GPIO_OSPEEDR_OSPEED1;
	GPIOA->MODER &= ~GPIO_MODER_MODER1;
	GPIOA->MODER |= (3 << GPIO_MODER_MODER1_Pos);
	
	// Set up I2S
	// PA6: MCK (SCK)
	// PB12: WS (LRCK)
	// PB13: CK (BCK)
	// PB15: SD (DATA)
	GPIOA->MODER &= ~GPIO_MODER_MODER6;
	GPIOA->MODER |= GPIO_MODER_MODER6_1;
	
	GPIOB->MODER &= ~GPIO_MODER_MODER12;
	GPIOB->MODER |= GPIO_MODER_MODER12_1;
	
	GPIOB->MODER &= ~GPIO_MODER_MODER13;
	GPIOB->MODER |= GPIO_MODER_MODER13_1;
	
	GPIOB->MODER &= ~GPIO_MODER_MODER15;
	GPIOB->MODER |= GPIO_MODER_MODER15_1;
	
	GPIOA->AFR[0] &= ~GPIO_AFRL_AFSEL6;
	GPIOA->AFR[0] |= 6 << GPIO_AFRL_AFSEL6_Pos;
	
	GPIOB->AFR[1] &= ~GPIO_AFRH_AFSEL12;
	GPIOB->AFR[1] |= 5 << GPIO_AFRH_AFSEL12_Pos;
	
	GPIOB->AFR[1] &= ~GPIO_AFRH_AFSEL13;
	GPIOB->AFR[1] |= 5 << GPIO_AFRH_AFSEL13_Pos;
	
	GPIOB->AFR[1] &= ~GPIO_AFRH_AFSEL15;
	GPIOB->AFR[1] |= 5 << GPIO_AFRH_AFSEL15_Pos;
	
	// Set up interface for indicator LEDs
	// PB6 and PB5
	GPIOB->MODER &= ~GPIO_MODER_MODER6;
    GPIOB->MODER |= 1 << GPIO_MODER_MODER6_Pos;
    GPIOB->MODER &= ~GPIO_MODER_MODER5;
    GPIOB->MODER |= 1 << GPIO_MODER_MODER5_Pos;
    
	// Feedback status LED
	GPIOC->MODER &= ~GPIO_MODER_MODER13;
	GPIOC->MODER |= 1 << GPIO_MODER_MODER13_Pos;
    
    // Set alternate functions for USB_OTG pins
	// PA11: DM (AF10)
	// PA12: DP (AF10)
	GPIOA->MODER &= ~GPIO_MODER_MODER11;
	GPIOA->MODER |= GPIO_MODER_MODER11_1;
	
	GPIOA->MODER &= ~GPIO_MODER_MODER12;
	GPIOA->MODER |= GPIO_MODER_MODER12_1;
		
	GPIOA->AFR[1] &= ~GPIO_AFRH_AFSEL11;
	GPIOA->AFR[1] |= GPIO_AFRH_AFSEL11_1 | GPIO_AFRH_AFSEL11_3;
	
	GPIOA->AFR[1] &= ~GPIO_AFRH_AFSEL12;
	GPIOA->AFR[1] |= GPIO_AFRH_AFSEL12_1 | GPIO_AFRH_AFSEL12_3;
	
	// Alternate function for external trigger for TIM2
	GPIOA->MODER &= ~GPIO_MODER_MODER5;
	GPIOA->MODER |= 2 << GPIO_MODER_MODER5_Pos;
	GPIOA->AFR[0] &= ~GPIO_AFRL_AFSEL5;
	GPIOA->AFR[0] |= 1 << GPIO_AFRL_AFSEL5_Pos;
	
	// Buttons
	// Button 1 (scan backward): PB1
	// Button 2 (Play/pause):    PB2
	// Button 3 (Scan forward):  PA4
	// Button 4 (Mute):          PB0
	GPIOA->MODER &= ~GPIO_MODER_MODER4;
	GPIOB->MODER &= ~GPIO_MODER_MODER0;
	GPIOB->MODER &= ~GPIO_MODER_MODER1;
	GPIOB->MODER &= ~GPIO_MODER_MODER2;
	
	// Activate pull-ups on pushbuttons
	GPIOA->PUPDR &= ~GPIO_PUPDR_PUPDR4;
	GPIOA->PUPDR |= GPIO_PUPDR_PUPDR4_0;
	GPIOB->PUPDR &= ~GPIO_PUPDR_PUPDR0;
	GPIOB->PUPDR |= GPIO_PUPDR_PUPDR0_0;
	GPIOB->PUPDR &= ~GPIO_PUPDR_PUPDR1;
	GPIOB->PUPDR |= GPIO_PUPDR_PUPDR1_0;
	
	// LEDs
	// PB4: Play
	// PB3: Mute
	GPIOB->MODER &= ~GPIO_MODER_MODER3;
	GPIOB->MODER |= 1 << GPIO_MODER_MODER3_Pos;
	GPIOB->MODER &= ~GPIO_MODER_MODER4;
	GPIOB->MODER |= 1 << GPIO_MODER_MODER4_Pos;
	
	// VU LEDs
	// VU1: PA2
	// VU2: PA3
	// VU3: PA7
	// VU4: PA8
	// VU5: PA10
	// VU6: PB7
	// VU7: PB8
	// VU8: PB9
	// VU9: PB10
	// VU10: PC14
	// Channel select: PC15
	GPIOA->MODER &= ~GPIO_MODER_MODER2;
	GPIOA->MODER |= 1 << GPIO_MODER_MODER2_Pos;
	GPIOA->MODER &= ~GPIO_MODER_MODER3;
	GPIOA->MODER |= 1 << GPIO_MODER_MODER3_Pos;
	GPIOA->MODER &= ~GPIO_MODER_MODER7;
	GPIOA->MODER |= 1 << GPIO_MODER_MODER7_Pos;
	GPIOA->MODER &= ~GPIO_MODER_MODER8;
	GPIOA->MODER |= 1 << GPIO_MODER_MODER8_Pos;
	GPIOA->MODER &= ~GPIO_MODER_MODER10;
	GPIOA->MODER |= 1 << GPIO_MODER_MODER10_Pos;
	GPIOB->MODER &= ~GPIO_MODER_MODER7;
	GPIOB->MODER |= 1 << GPIO_MODER_MODER7_Pos;
	GPIOB->MODER &= ~GPIO_MODER_MODER8;
	GPIOB->MODER |= 1 << GPIO_MODER_MODER8_Pos;
	GPIOB->MODER &= ~GPIO_MODER_MODER9;
	GPIOB->MODER |= 1 << GPIO_MODER_MODER9_Pos;
	GPIOB->MODER &= ~GPIO_MODER_MODER10;
	GPIOB->MODER |= 1 << GPIO_MODER_MODER10_Pos;
	GPIOC->MODER &= ~GPIO_MODER_MODER14;
	GPIOC->MODER |= 1 << GPIO_MODER_MODER14_Pos;
	GPIOC->MODER &= ~GPIO_MODER_MODER15;
	GPIOC->MODER |= 1 << GPIO_MODER_MODER15_Pos;
	
	// RELAY pin
	// PB14
	GPIOB->MODER &= ~GPIO_MODER_MODER14;
	GPIOB->MODER |= 1 << GPIO_MODER_MODER14_Pos;
	GPIOB->PUPDR &= ~GPIO_PUPDR_PUPDR14;
	GPIOB->PUPDR |= GPIO_PUPDR_PUPDR14_0;
	
}

int main (void) {

	SystemInit();
	ClockInit();
	SystemCoreClockUpdate();
	(void) SysTick_Config(SystemCoreClock / 1000);
	GPIOInit();
	ShutdownCtlInit();
	
	// Make sure output relay is switched off
	GPIOB->BSRR |= GPIO_BSRR_BR14;
	
	// Disable PLAY and MUTE LEDs
	GPIOB->BSRR |= GPIO_BSRR_BR4;
	GPIOB->BSRR |= GPIO_BSRR_BR3;
	
	// Set sampling rate indicator to 44.1 kHz
	GPIOB->BSRR |= GPIO_BSRR_BR5;
	GPIOB->BSRR |= GPIO_BSRR_BR6;
	
	// Reset all VU LEDs
	GPIOA->BSRR |= GPIO_BSRR_BR2;
	GPIOA->BSRR |= GPIO_BSRR_BR3;
	GPIOA->BSRR |= GPIO_BSRR_BR7;
	GPIOA->BSRR |= GPIO_BSRR_BR8;
	GPIOA->BSRR |= GPIO_BSRR_BR10;
	GPIOB->BSRR |= GPIO_BSRR_BR7;
	GPIOB->BSRR |= GPIO_BSRR_BR8;
	GPIOB->BSRR |= GPIO_BSRR_BR9;
	GPIOB->BSRR |= GPIO_BSRR_BR10;
	GPIOC->BSRR |= GPIO_BSRR_BR14;
	
	debounceInit();
	
#ifdef DEBUG
	USARTInit(115200);
	printMsg("\r\nStart of initialization\r\n");
#endif

	AudioInit();
	USBDeviceInit();
	
	// Run a LED ramp sequence at startup to show all LEDs are operational
	GPIOC->BSRR |= GPIO_BSRR_BR13;
	delay_ms(100);
	GPIOC->BSRR |= GPIO_BSRR_BS13;
	
	GPIOC->BSRR |= GPIO_BSRR_BR15;
	delay_ms(1);
	
	GPIOA->BSRR |= GPIO_BSRR_BS2;
	delay_ms(50);
	GPIOA->BSRR |= GPIO_BSRR_BS3;
	delay_ms(50);
	GPIOA->BSRR |= GPIO_BSRR_BS7;
	delay_ms(50);
	GPIOA->BSRR |= GPIO_BSRR_BS8;
	delay_ms(50);
	GPIOA->BSRR |= GPIO_BSRR_BS10;
	delay_ms(50);
	GPIOB->BSRR |= GPIO_BSRR_BS7;
	delay_ms(50);
	GPIOB->BSRR |= GPIO_BSRR_BS8;
	delay_ms(50);
	GPIOB->BSRR |= GPIO_BSRR_BS9;
	delay_ms(50);
	GPIOB->BSRR |= GPIO_BSRR_BS10;
	delay_ms(50);
	GPIOC->BSRR |= GPIO_BSRR_BS14;
	delay_ms(50);
	GPIOC->BSRR |= GPIO_BSRR_BS15;
	delay_ms(50);
	GPIOC->BSRR |= GPIO_BSRR_BR14;
	delay_ms(50);
	GPIOB->BSRR |= GPIO_BSRR_BR10;
	delay_ms(50);
	GPIOB->BSRR |= GPIO_BSRR_BR9;
	delay_ms(50);
	GPIOB->BSRR |= GPIO_BSRR_BR8;
	delay_ms(50);
	GPIOB->BSRR |= GPIO_BSRR_BR7;
	delay_ms(50);
	GPIOA->BSRR |= GPIO_BSRR_BR10;
	delay_ms(50);
	GPIOA->BSRR |= GPIO_BSRR_BR8;
	delay_ms(50);
	GPIOA->BSRR |= GPIO_BSRR_BR7;
	delay_ms(50);
	GPIOA->BSRR |= GPIO_BSRR_BR3;
	delay_ms(50);
	GPIOA->BSRR |= GPIO_BSRR_BR2;
	
	ADCInit();
	LEDRampInit();
	
	delay_ms(1000);
	
	// Switch on output relay
	GPIOB->BSRR |= GPIO_BSRR_BS14;
	
    while (1) {
        //__WFI(); // Wait for interrupt
    }

    // Return 0 to satisfy compiler
    return 0;
}

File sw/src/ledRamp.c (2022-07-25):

#include "stm32f4xx.h"
#include "adc.h"
#include "ledRamp.h"

#define MAXVAL		4000
#define NLEDS		10
#define STEP		2

#define	TIMEOUT		100

// -40, -20, -10, -7, -5, -3, -1, 0, +3, +6 dB
int				thresholds[NLEDS] = {20, 200, 632, 893, 1125, 1416, 1783, 2000, 2825, 4000};
volatile int	channel, peakVal[2], timeout[2];

// LEDs: A2, A3, A7, A8, A10, B7, B8, B9, B10, C14
// Row selector: C15

void LEDRampInit(void) {
	
	channel = 0;
	peakVal[0] = peakVal[1] = -1;
	timeout[0] = timeout[1] = 0;
	
	// Set up timer 4 to update the LED ramp
	RCC->APB1ENR |= RCC_APB1ENR_TIM4EN;
	
	// Run timer at 200 Hz
	TIM4->PSC = 4800 - 1;
	TIM4->ARR = 50 - 1;
	TIM4->CNT = 0;
		
	// Timer 4 update interrupt enable
	TIM4->DIER |= TIM_DIER_UIE;
	
	NVIC_EnableIRQ(TIM4_IRQn);
	
	// Enable Timer 4
	TIM4->CR1 |= TIM_CR1_CEN;
	
}

void TIM4_IRQHandler(void) {  

	int	val, level;
		
	channel = (channel + 1) % 2;
		
	val = ADCRead(channel);
		
	level = setLEDRampVal(val);
		
	timeout[channel] += 1;
		
	if(level < peakVal[channel]) {
		if(timeout[channel] < TIMEOUT)
			setLEDPeakVal(peakVal[channel]);
		else {
			timeout[channel] = 0;
			peakVal[channel] = -1;
		}
	}
	else {
		peakVal[channel] = level;
		timeout[channel] = 0;
	}
		
	if(channel)
		GPIOC->BSRR |= GPIO_BSRR_BR15;
	else
		GPIOC->BSRR |= GPIO_BSRR_BS15;

	if(TIM4->SR & TIM_SR_UIF)
		TIM4->SR &= ~TIM_SR_UIF;

}
	
int setLEDRampVal(int val) {
	
	int		level;
	
	if(val > thresholds[9]) {
		GPIOA->BSRR |= GPIO_BSRR_BS2;
		GPIOA->BSRR |= GPIO_BSRR_BS3;
		GPIOA->BSRR |= GPIO_BSRR_BS7;
		GPIOA->BSRR |= GPIO_BSRR_BS8;
		GPIOA->BSRR |= GPIO_BSRR_BS10;
		GPIOB->BSRR |= GPIO_BSRR_BS7;
		GPIOB->BSRR |= GPIO_BSRR_BS8;
		GPIOB->BSRR |= GPIO_BSRR_BS9;
		GPIOB->BSRR |= GPIO_BSRR_BS10;
		GPIOC->BSRR |= GPIO_BSRR_BS14;
		level = 9;
	}
	else if(val > thresholds[8]) {
		GPIOA->BSRR |= GPIO_BSRR_BS2;
		GPIOA->BSRR |= GPIO_BSRR_BS3;
		GPIOA->BSRR |= GPIO_BSRR_BS7;
		GPIOA->BSRR |= GPIO_BSRR_BS8;
		GPIOA->BSRR |= GPIO_BSRR_BS10;
		GPIOB->BSRR |= GPIO_BSRR_BS7;
		GPIOB->BSRR |= GPIO_BSRR_BS8;
		GPIOB->BSRR |= GPIO_BSRR_BS9;
		GPIOB->BSRR |= GPIO_BSRR_BS10;
		GPIOC->BSRR |= GPIO_BSRR_BR14;
		level = 8;
	}
	else if(val > thresholds[7]) {
		GPIOA->BSRR |= GPIO_BSRR_BS2;
		GPIOA->BSRR |= GPIO_BSRR_BS3;
		GPIOA->BSRR |= GPIO_BSRR_BS7;
		GPIOA->BSRR |= GPIO_BSRR_BS8;
		GPIOA->BSRR |= GPIO_BSRR_BS10;
		GPIOB->BSRR |= GPIO_BSRR_BS7;
		GPIOB->BSRR |= GPIO_BSRR_BS8;
		GPIOB->BSRR |= GPIO_BSRR_BS9;
		GPIOB->BSRR |= GPIO_BSRR_BR10;
		GPIOC->BSRR |= GPIO_BSRR_BR14;
		level = 7;
	}
	else if(val > thresholds[6]) {
		GPIOA->BSRR |= GPIO_BSRR_BS2;
		GPIOA->BSRR |= GPIO_BSRR_BS3;
		GPIOA->BSRR |= GPIO_BSRR_BS7;
		GPIOA->BSRR |= GPIO_BSRR_BS8;
		GPIOA->BSRR |= GPIO_BSRR_BS10;
		GPIOB->BSRR |= GPIO_BSRR_BS7;
		GPIOB->BSRR |= GPIO_BSRR_BS8;
		GPIOB->BSRR |= GPIO_BSRR_BR9;
		GPIOB->BSRR |= GPIO_BSRR_BR10;
		GPIOC->BSRR |= GPIO_BSRR_BR14;
		level = 6;
	}
	else if(val > thresholds[5]) {
		GPIOA->BSRR |= GPIO_BSRR_BS2;
		GPIOA->BSRR |= GPIO_BSRR_BS3;
		GPIOA->BSRR |= GPIO_BSRR_BS7;
		GPIOA->BSRR |= GPIO_BSRR_BS8;
		GPIOA->BSRR |= GPIO_BSRR_BS10;
		GPIOB->BSRR |= GPIO_BSRR_BS7;
		GPIOB->BSRR |= GPIO_BSRR_BR8;
		GPIOB->BSRR |= GPIO_BSRR_BR9;
		GPIOB->BSRR |= GPIO_BSRR_BR10;
		GPIOC->BSRR |= GPIO_BSRR_BR14;
		level = 5;
	}
	else if(val > thresholds[4]) {
		GPIOA->BSRR |= GPIO_BSRR_BS2;
		GPIOA->BSRR |= GPIO_BSRR_BS3;
		GPIOA->BSRR |= GPIO_BSRR_BS7;
		GPIOA->BSRR |= GPIO_BSRR_BS8;
		GPIOA->BSRR |= GPIO_BSRR_BS10;
		GPIOB->BSRR |= GPIO_BSRR_BR7;
		GPIOB->BSRR |= GPIO_BSRR_BR8;
		GPIOB->BSRR |= GPIO_BSRR_BR9;
		GPIOB->BSRR |= GPIO_BSRR_BR10;
		GPIOC->BSRR |= GPIO_BSRR_BR14;
		level = 4;
	}
	else if(val > thresholds[3]) {
		GPIOA->BSRR |= GPIO_BSRR_BS2;
		GPIOA->BSRR |= GPIO_BSRR_BS3;
		GPIOA->BSRR |= GPIO_BSRR_BS7;
		GPIOA->BSRR |= GPIO_BSRR_BS8;
		GPIOA->BSRR |= GPIO_BSRR_BR10;
		GPIOB->BSRR |= GPIO_BSRR_BR7;
		GPIOB->BSRR |= GPIO_BSRR_BR8;
		GPIOB->BSRR |= GPIO_BSRR_BR9;
		GPIOB->BSRR |= GPIO_BSRR_BR10;
		GPIOC->BSRR |= GPIO_BSRR_BR14;
		level = 3;
	}
	else if(val > thresholds[2]) {
		GPIOA->BSRR |= GPIO_BSRR_BS2;
		GPIOA->BSRR |= GPIO_BSRR_BS3;
		GPIOA->BSRR |= GPIO_BSRR_BS7;
		GPIOA->BSRR |= GPIO_BSRR_BR8;
		GPIOA->BSRR |= GPIO_BSRR_BR10;
		GPIOB->BSRR |= GPIO_BSRR_BR7;
		GPIOB->BSRR |= GPIO_BSRR_BR8;
		GPIOB->BSRR |= GPIO_BSRR_BR9;
		GPIOB->BSRR |= GPIO_BSRR_BR10;
		GPIOC->BSRR |= GPIO_BSRR_BR14;
		level = 2;
	}
	else if(val > thresholds[1]) {
		GPIOA->BSRR |= GPIO_BSRR_BS2;
		GPIOA->BSRR |= GPIO_BSRR_BS3;
		GPIOA->BSRR |= GPIO_BSRR_BR7;
		GPIOA->BSRR |= GPIO_BSRR_BR8;
		GPIOA->BSRR |= GPIO_BSRR_BR10;
		GPIOB->BSRR |= GPIO_BSRR_BR7;
		GPIOB->BSRR |= GPIO_BSRR_BR8;
		GPIOB->BSRR |= GPIO_BSRR_BR9;
		GPIOB->BSRR |= GPIO_BSRR_BR10;
		GPIOC->BSRR |= GPIO_BSRR_BR14;
		level = 1;
	}
	else if(val > thresholds[0]) {
		GPIOA->BSRR |= GPIO_BSRR_BS2;
		GPIOA->BSRR |= GPIO_BSRR_BR3;
		GPIOA->BSRR |= GPIO_BSRR_BR7;
		GPIOA->BSRR |= GPIO_BSRR_BR8;
		GPIOA->BSRR |= GPIO_BSRR_BR10;
		GPIOB->BSRR |= GPIO_BSRR_BR7;
		GPIOB->BSRR |= GPIO_BSRR_BR8;
		GPIOB->BSRR |= GPIO_BSRR_BR9;
		GPIOB->BSRR |= GPIO_BSRR_BR10;
		GPIOC->BSRR |= GPIO_BSRR_BR14;
		level = 0;
	}
	else {
		GPIOA->BSRR |= GPIO_BSRR_BR2;
		GPIOA->BSRR |= GPIO_BSRR_BR3;
		GPIOA->BSRR |= GPIO_BSRR_BR7;
		GPIOA->BSRR |= GPIO_BSRR_BR8;
		GPIOA->BSRR |= GPIO_BSRR_BR10;
		GPIOB->BSRR |= GPIO_BSRR_BR7;
		GPIOB->BSRR |= GPIO_BSRR_BR8;
		GPIOB->BSRR |= GPIO_BSRR_BR9;
		GPIOB->BSRR |= GPIO_BSRR_BR10;
		GPIOC->BSRR |= GPIO_BSRR_BR14;
		level = -1;
	}
	
	return level;
}

void setLEDPeakVal(int val) {
	
	switch(val) {
		case 0:
			GPIOA->BSRR |= GPIO_BSRR_BS2;
			break;
		case 1:
			GPIOA->BSRR |= GPIO_BSRR_BS3;
			break;
		case 2:
			GPIOA->BSRR |= GPIO_BSRR_BS7;
			break;
		case 3:
			GPIOA->BSRR |= GPIO_BSRR_BS8;
			break;
		case 4:
			GPIOA->BSRR |= GPIO_BSRR_BS10;
			break;
		case 5:
			GPIOB->BSRR |= GPIO_BSRR_BS7;
			break;
		case 6:
			GPIOB->BSRR |= GPIO_BSRR_BS8;
			break;
		case 7:
			GPIOB->BSRR |= GPIO_BSRR_BS9;
			break;
		case 8:
			GPIOB->BSRR |= GPIO_BSRR_BS10;
			break;
		case 9:
			GPIOC->BSRR |= GPIO_BSRR_BS14;
			break;
	}
}

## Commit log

2022-07-25 Add code
    [AmplifierClassA.kicad_pcb, AmplifierClassA.kicad_sch, LEDboard.kicad_pcb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]
2022-08-01 Added schematic images
